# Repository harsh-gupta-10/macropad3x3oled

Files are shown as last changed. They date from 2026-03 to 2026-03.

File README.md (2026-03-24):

# Macropad 3×3 OLED

A 3×3 mechanical switch macropad with rotary encoders and OLED display, designed with CircuitPython on RP2040. Started as hand-wired prototype, evolving toward custom PCB design.

> **Repository**: https://github.com/harsh-gupta-10/macropad3x3oled

## Overview

This project documents the full design and build process for a compact macropad. Currently running as a functional hand-wired prototype with 9 programmable keys, 2 rotary encoders, and a 1.3" OLED display. The design is being formalized into a custom PCB using KiCAD 8.0 and JLCPCB manufacturing.

**Current status:** Hand-wired prototype complete and working. KiCAD schematic in progress.

## Features

- 3×3 mechanical switch grid (9 keys total)
- 2× EC11 rotary encoders with push buttons
- 1.3" I2C OLED display (SSD1306)
- 6 programmable layers (56 shortcuts total)
- USB Type-C connection
- CircuitPython firmware, fully modular
- Hot-configurable macros (no reflashing needed)

## Hardware Overview

**Current prototype components:**

| Component | Qty | Notes |
|---|-----|---|
| RP2040 microcontroller | 1 | Raspberry Pi Pico or compatible |
| Mechanical switches (MX) | 9 | User choice; same profile |
| EC11 rotary encoders | 2 | With integrated push switch |
| SSD1306 OLED display | 1 | 1.3" I2C interface |
| 1N4148 diodes | ~10 | Anti-ghosting matrix diodes |
| USB Type-C breakout | 1 | For power and data |
| Hook-up wire (22 AWG) | — | Solid core preferred |

**Key design notes:**
- Matrix scanning: 3 rows + 3 columns = 9 keys with just 6 GPIO pins
- I2C protocol: 2 wires (SDA, SCL) with 4.7kΩ pull-up resistors
- Power: 5V USB → 3.3V logic via linear regulator
- Debouncing: Software-based (20ms typical)

---

## Firmware Overview

Using CircuitPython on RP2040 for firmware. Clean Python implementation without build systems.

**Core functionality:**
- Matrix scanning: Reads 3×3 switch array, debounces input
- Encoder handling: Gray code decoding for 2 rotary encoders
- I2C display: Layer indicator and status on OLED
- USB HID: Presents as standard keyboard to operating system

**Firmware features:**
- 6 programmable layers for macro storage
- Real-time layer switching via encoder
- Per-key configurable actions
- Modular design (RGB, wireless support can be added)
- Configuration stored in `config.py`

## Usage / Workflow

**Basic operation:**
1. Connect via USB → device appears as keyboard
2. Press keys to trigger mapped macros/commands
3. Rotate encoders to switch layers or control functions
4. OLED shows current active layer

**Configuration:**
- Edit `config.py` in CircuitPython file system
- Reload to apply changes
- No firmware reflash needed

**Workflow example:**
- Layer 1: Productivity shortcuts (Alt+Tab, Copy/Paste, etc.)
- Layer 2: Media controls (Play, Volume, Next)
- Layer 3: Application launcher shortcuts
- Switch layers by rotating encoder

---

## Design & Build

### Hand-Wired Prototype Status

Current build is fully functional hand-wired setup. Validates all design decisions before PCB manufacturing.

**Current state:**
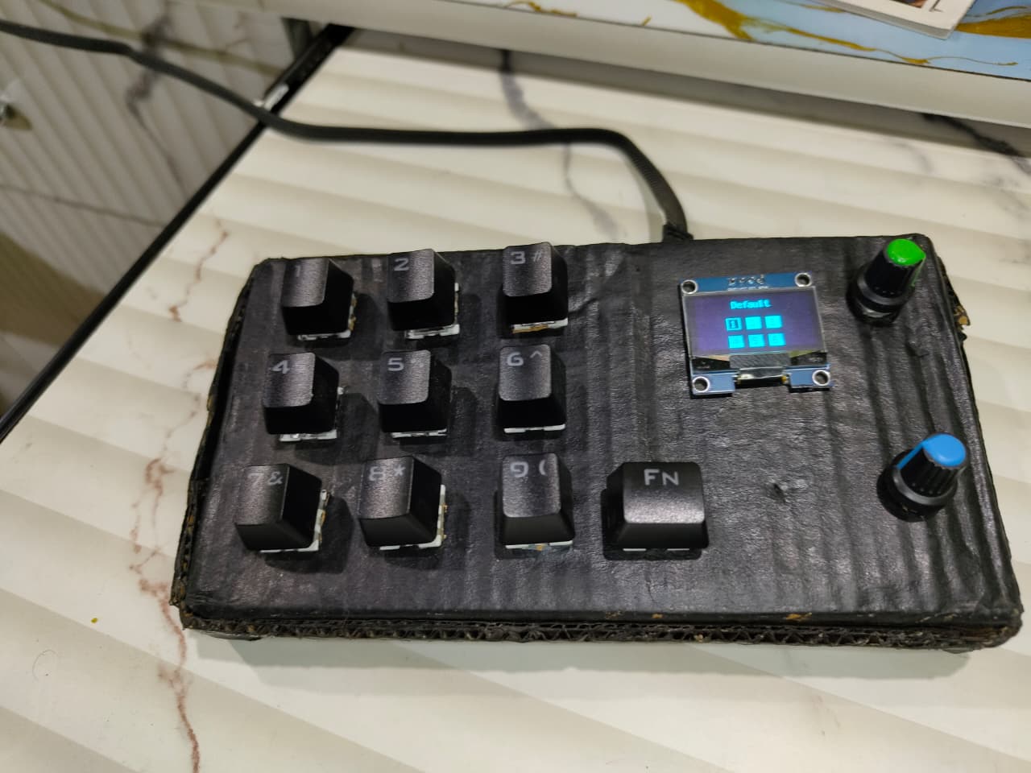
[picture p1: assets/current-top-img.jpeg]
Top view
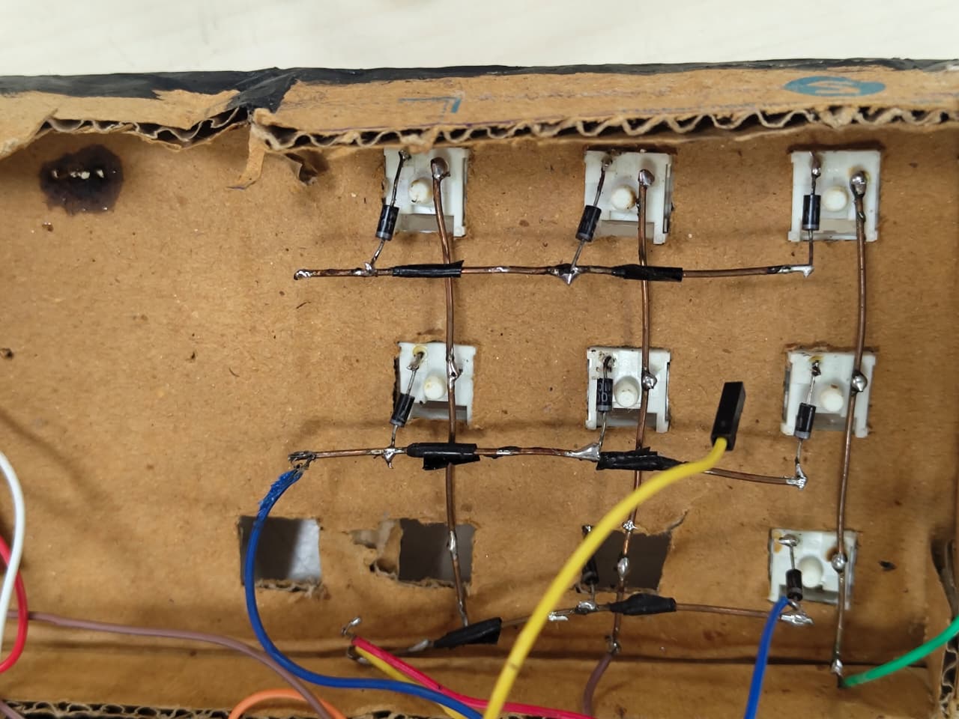
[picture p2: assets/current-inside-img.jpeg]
Internal view
 

### PCB / Schematic Design

Formalizing the design in KiCAD 8.0 for manufacturing through JLCPCB.

**Schematic phase:**
- Component selection and library setup
- Connection documentation (nets)
- Electrical rule checking (ERC)
- Footprint assignment

**Layout phase:**
- 2-layer PCB design (top: signals, bottom: ground plane)
- Design rules: 0.25mm trace width, 0.2mm clearance
- Dense ground via placement
- Manufacturing constraints (1mm board edge minimum)

**Signal integrity considerations:**
- I2C traces (SDA/SCL) routed together
- USB traces kept short and clean
- Test points for hardware debugging
- Decoupling capacitors near all power pins

**Manufacturing:**
- Gerber file generation from KiCAD
- Pre-order verification using Gerber viewers
- JLCPCB ordering: $5-20 for 5 prototype boards
- Expected turnaround: 7-10 days

### CAD / Design Files

The hardware case and enclosure are under development:
- Base design: `cad/macropad base v0.f3d` (Fusion 360)
- Top design: `cad/macro pad v3 top final.f3d` (Fusion 360)
- 3D printable base: `production/macropad base stl.3mf`

Files are in the `cad/` and `production/` directories. 3D printing materials: PLA or PETG recommended.

---

## BOM (Bill of Materials)

**Prototype assembly cost: $50-65 usd i got pricing from amazon.com(But in india i got all this under 25 usd)**

| Item | Qty | Unit Cost | Total | Source |
|---|-----|---|---|---|
| Mechanical switches (MX) | 9 | $1 | $9 | Outemu switches 2 pins |
| Keycaps (1u profile) | 1 set | $10-30 | $20 | Matched to switch type |
| EC11 rotary encoders | 2 | $3 | $6 | With push switch |
| SSD1306 OLED 1.3" display | 1 | $5 | $5 | I2C interface |
| RP2040 microcontroller | 1 | $5 | $5 | Raspberry Pi Pico |
| USB Type-C breakout board | 1 | $3 | $3 | For future PCB |
| 1N4148 signal diodes | 10 | $0.20 | $2 | Anti-ghosting matrix |
| Hook-up wire (22 AWG) | 1 spool | $5 | $5 | Solid core |
| USB cable | 1 | $3 | $3 | Programming/power |
| 3D printer filament | 50-100g | $0.02/g | $1-3 | PLA or PETG |
| **Total** | — | — | **$50-65** | — |

**PCB manufacturing (future):**
- Board fabrication: $5-20 for 5 boards via JLCPCB
- Component cost per unit: $30-40 
- Full assembled board cost (future): $50-60 per unit

---

## Future Improvements

- **4-layer PCB** — Better power distribution, reduced EMI
- **RGB LED matrix** — WS2812B per-key addressable LEDs
- **Metal enclosure** — CNC-milled aluminum case
- **Wireless support** — RP2040-W variant with Bluetooth
- **Battery charging** — LiPo connector with charge IC
- **Potentiometer option** — Analog knob instead of encoder
- **Configuration UI** — Desktop app for macro programming
- **Backlight** — Per-key or underglow LED strips

---

## Images / Gallery

**Current prototype build:**
- Top view: 
- Internal view: 
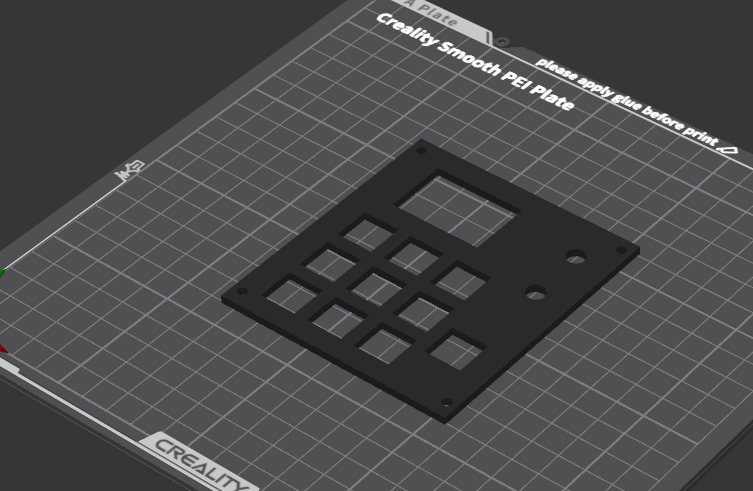
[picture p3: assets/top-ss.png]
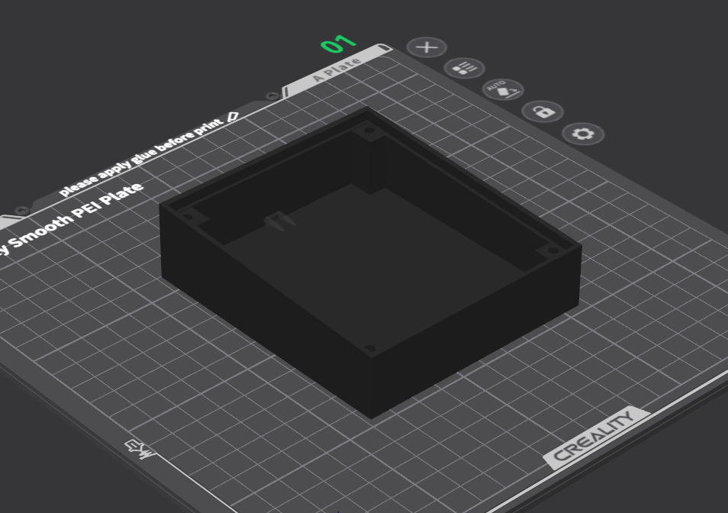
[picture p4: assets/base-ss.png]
- Reference photos:  

---

## Repo / Links

- **GitHub Repository**: https://github.com/harsh-gupta-10/macropad3x3oled
- **Raspberry Pi Pico Documentation**: https://www.raspberrypi.org/documentation/microcontrollers/raspberry-pi-pico.html
- **CircuitPython**: https://circuitpython.org/
- **KiCAD**: https://www.kicad.org/

---

##  Acknowledgements

Resources used:
- Raspberry Pi Foundation (RP2040 documentation)
- Circuit Python community
- KiCAD open-source PCB design tools

---

## License

MIT License - Feel free to use this design for your own projects.

See LICENSE file for details.

- Check diode orientation (trust me, you'll get this wrong)
- Test one key in isolation with a multimeter
- Verify GPIO pins match what the code expects
- That loose wire you "fixed" earlier? Check it again

### OLED display shows nothing

**Panic level:** Moderate

- I2C address mismatch? Run the I2C scanner code
- Pull-up resistors missing? Add 4.7kΩ on SDA and SCL
- Wrong I2C pins? Check code vs wiring
- Display DOA? Try another one (happened to me)

### Encoder spinning but not detecting

This one is fun:

- Gray code logic wrong? Complex but traceable
- Debounce timing too aggressive? Try different values
- Continuity bad? Test each pin with multimeter
- Encoder defect? Swap it out and test

### PCB doesn't work after assembly

**This is the fun one:**

- Cold solder joints? Use more flux and reheat
- Continuity bad? Multimeter everything
- Component orientation wrong? Some parts care deeply (ICs)
- Wrong component values? Double-check BOM vs assembled board
- Power OK but nothing works? Ground plane problem (probably)

### General debugging philosophy

1. Power first — Is there actually voltage where there should be?
2. Ground second — Is ground actually connected?
3. Logic third — Are signals even reaching their destinations?
4. Code last — Because 99% of the time it's hardware

Also, take a break before debugging. Frustrated you makes worse decisions.

---

## Contributing

I'd actually love feedback, suggestions, or just hearing about your own PCB adventures.

**Issues/PRs welcome for:**
- Design improvements (better component placement, better routing)
- Firmware enhancements
- Documentation clarifications
- "Hey I did this too" stories
- Cheaper alternative components
- Anything I'm doing wrong (seriously though)

---

## License

This project is open source. See the repository for details.

---

**Built by [Harsh Gupta](https://github.com/harsh-gupta-10)** ⌨️

If you're thinking about learning PCB design: start with something you actually want to use. Make it work first with whatever you have. Then make it pretty. The learning comes from the iteration, not the destination.

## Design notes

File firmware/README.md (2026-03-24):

# 🎛️ MacroPad RP2040 — Firmware

<p align="center">
  <b>Custom CircuitPython firmware for a DIY 3×3 macro pad built on the RP2040</b>
</p>

<p align="center">
  
  
  
</p>

> **Companion Software →** [MacroPad Configurator (Python + Tkinter)](https://github.com/harsh-gupta-10/macropad-software-python-tkinter)

---

## ✨ Features

| Feature | Details |
|---|---|
| **9-Key Matrix** | 3×3 cherry-style key grid with full per-key configurability |
| **6 Profiles** | Each profile stores 9 independent key actions, switchable on the fly |
| **OLED Display** | SH1106 128×64 showing profile selector bubbles + logo icon previews |
| **2 Rotary Encoders** | Volume control + profile navigation with rotate / click / hold actions |
| **Mic Toggle** | Dedicated button for mic mute (default: F13) |
| **JSON-Driven Config** | All key mappings and settings live in editable JSON files on the drive |

### Action Types

- ⌨️ **Keyboard Shortcuts** — single key or multi-key combo (e.g. `Ctrl+Shift+Esc`)
- 🚀 **Launch Software** — opens any app via Windows search (e.g. `notepad`, `chrome`)
- 📝 **Text Macros** — type text in single / line-by-line / paragraph mode, with optional Shift+Enter for apps like WhatsApp
- 🔊 **Media Controls** — volume up/down, mute, play/pause

---

## 📁 Project Structure

```text
├── code.py               # Main CircuitPython loop (display, matrix, encoders)
├── keyout.py             # Action engine (combos, software launch, text typing)
├── keysfile.json         # Profile + key action definitions (9 keys × 6 profiles)
├── special-keyout.json   # Encoder & mic button mappings
├── img/                  # BMP icons for OLED profile preview
│   ├── youtube-logo-bmp.bmp
│   ├── vscode-logo-bmp.bmp
│   ├── obs-logo-bmp.bmp
│   ├── volt-logo-bmp.bmp
│   ├── windows-logo-bmp.bmp
│   └── photoshop-logo-bmp.bmp
├── lib/                  # CircuitPython libraries
│   ├── adafruit_hid/
│   ├── adafruit_display_text/
│   ├── adafruit_displayio_sh1106.mpy
│   └── ...
├── main.py               # Legacy KMK firmware (inactive when code.py exists)
└── settings.toml         # CircuitPython board settings
```

---

## 🔌 Hardware Wiring

### OLED Display (SH1106, I2C, address `0x3C`)

| Signal | Pin |
|---|-----|
| SCL | GP9 |
| SDA | GP8 |

### Encoder 1 — Volume

| Signal | Pin |
|---|-----|
| A / B | GP14, GP15 |
| Button | GP17 |

### Encoder 2 — Display / Profile (Software Quadrature)

| Signal | Pin |
|---|-----|
| A / B | GP18, GP19 |
| Button | GP20 |

### Mic Toggle Button

| Signal | Pin |
|---|-----|
| Button | GP0 |

### 3×3 Key Matrix

| | GP1 (Col 0) | GP2 (Col 1) | GP3 (Col 2) |
|---|---|---|---|
| **GP4 (Row 0)** | Key 1 | Key 4 | Key 7 |
| **GP13 (Row 1)** | Key 3 | Key 6 | Key 9 |
| **GP6 (Row 2)** | Key 2 | Key 5 | Key 8 |

> 💡 If a physical button maps to the wrong action, edit `key_mapping` in `code.py` — don't rearrange `keysfile.json`.

---

## 🎮 Controls

| Input | Action |
|---|---|
| Encoder 1 — Rotate | Volume Up / Down |
| Encoder 1 — Click | Play / Pause |
| Encoder 1 — Hold (1s) | Mute |
| Encoder 2 — Rotate | Previous / Next Profile |
| Encoder 2 — Click | Switch Profile (shows icon for 1s) |
| Encoder 2 — Hold (1s) | Configurable special action |
| Mic Button | Toggle mic (default: F13) |
| Matrix Keys 1–9 | Execute current profile action |

---

## ⚙️ Configuration

### Profile Keys — `keysfile.json`

```json
{
  "settings": {
    "active_profiles": 6,
    "encoder_speeds": { "volume": 3, "display": 1 }
  },
  "profiles": {
    "0": {
      "1": { "name": "Close Tab", "key": ["ctrl", "w"] },
      "2": { "name": "Open VS Code", "key": ["windows"], "software": "vscode" },
      "3": {
        "name": "WhatsApp Msg",
        "key": ["text_input"],
        "action": "text_input",
        "text_content": "Hello!\nHow are you?",
        "text_type": "paragraph",
        "text_press_enter": true,
        "text_shift_enter": true
      }
    }
  }
}
```

**Action Formats:**

| Type | Required Fields |
|---|---|
| Key Combo | `key: ["ctrl", "s"]` |
| Software Launch | `key: ["windows"]`, `software: "notepad"` |
| Text Input | `action: "text_input"`, `text_content`, `text_type` (`single` / `line-by-line` / `paragraph`) |

> **`text_shift_enter: true`** — uses Shift+Enter for newlines instead of Enter. Essential for WhatsApp and similar apps where Enter sends the message.

### Special Inputs — `special-keyout.json`

```json
{
  "special_keys": {
    "volume_encoder_left":  { "name": "Volume Down", "key": ["media_volume_down"] },
    "display_encoder_right": { "name": "Next Profile", "action": "profile_next" }
  }
}
```

Each entry uses either `"key"` (keyboard/media token) or `"action"` (`profile_next`, `profile_prev`, `none`).

---

## 🚀 Getting Started

1. **Flash CircuitPython** onto your RP2040 board ([circuitpython.org](https://circuitpython.org/))
2. **Copy all project files** to the `CIRCUITPY` drive root
3. **Copy the `lib/` folder** to `CIRCUITPY/lib/`
4. **Edit your configs** — `keysfile.json` for key actions, `special-keyout.json` for encoders
5. **Save and go** — the board auto-reloads on file changes

> Use the companion [MacroPad Configurator](https://github.com/harsh-gupta-10/macropad-software-python-tkinter) app to edit profiles visually instead of hand-editing JSON.

---

## 🐛 Troubleshooting

| Problem | Fix |
|---|---|
| No key output | Confirm USB HID is detected by the OS. Check token spelling in JSON. |
| Wrong button mapping | Adjust `key_mapping` dict in `code.py` |
| Display not showing | Verify I2C wiring (GP9/GP8) and OLED address (`0x3C`) |
| Special actions not updating | Validate `special-keyout.json` syntax |
| Serial debug | Connect via serial console (e.g. PuTTY, `screen`) at 115200 baud |

---

## 📝 Notes

- Optimized for **Windows** shortcuts and search-bar-based software launching.
- `main.py` contains a legacy KMK firmware path — it does **not** run while `code.py` is present.
- Unsupported key tokens are logged over serial for easy debugging.

---

## 📄 License

MIT © [Harsh Gupta](https://github.com/harsh-gupta-10)

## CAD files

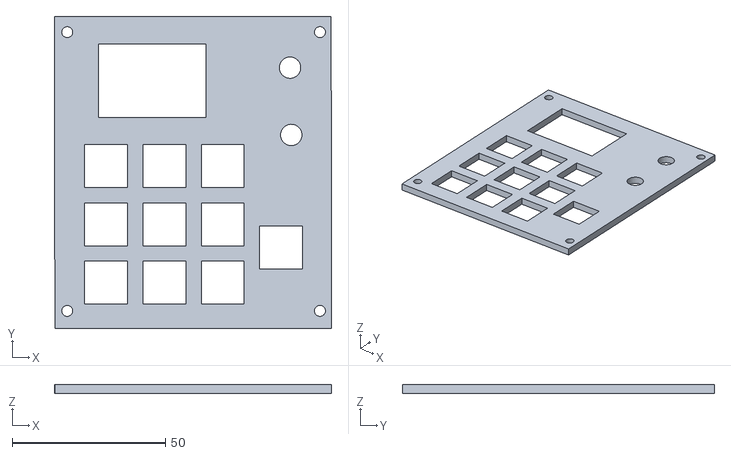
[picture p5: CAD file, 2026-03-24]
production/top macropad.stl
90.5 x 101.9 x 3.00

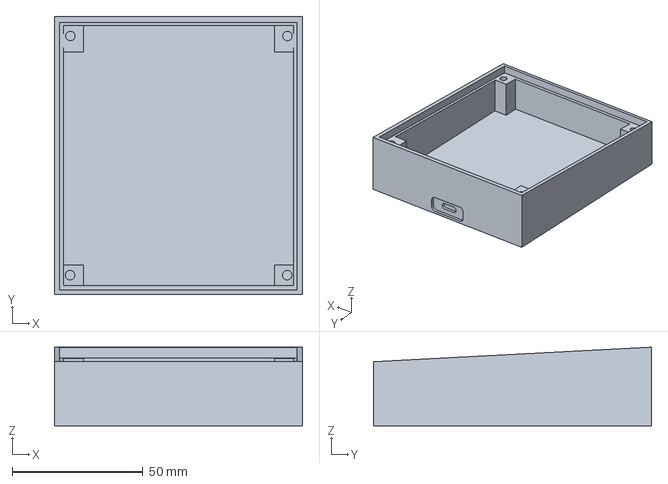
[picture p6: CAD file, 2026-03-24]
production/macropad base stl.3mf
94.9 x 106.4 x 30.1 mm

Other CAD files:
cad/macro pad v3 top final.f3d
cad/macropad base v0.f3d
production/macropad base stl.stl

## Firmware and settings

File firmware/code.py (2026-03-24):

import time
import json
import digitalio
import board
import busio
import usb_hid
import displayio
from adafruit_displayio_sh1106 import SH1106
from rotaryio import IncrementalEncoder
import terminalio
from adafruit_display_text import label
from digitalio import Direction, Pull
from adafruit_hid.consumer_control import ConsumerControl
from adafruit_hid.consumer_control_code import ConsumerControlCode
from adafruit_hid.keyboard import Keyboard
from adafruit_hid.keycode import Keycode
from keyout import execute_action

cc = ConsumerControl(usb_hid.devices)

encoder1 = IncrementalEncoder(board.GP14, board.GP15)
last_position_encoder1 = None

class SoftwareEncoder:
    def __init__(self, pinA, pinB):
        self.a = digitalio.DigitalInOut(pinA)
        self.b = digitalio.DigitalInOut(pinB)
        self.a.direction = digitalio.Direction.INPUT
        self.a.pull = digitalio.Pull.UP
        self.b.direction = digitalio.Direction.INPUT
        self.b.pull = digitalio.Pull.UP
        self.position = 0
        self._state = (int(self.a.value) << 1) | int(self.b.value)
        self._transition_accum = 0
        # Valid Gray-code transitions: +1/-1 quarter-steps, 0 for invalid/bounce.
        self._transition_table = (
            0, -1, 1, 0,
            1, 0, 0, -1,
            -1, 0, 0, 1,
            0, 1, -1, 0,
        )

    def update(self):
        current_state = (int(self.a.value) << 1) | int(self.b.value)
        if current_state != self._state:
            transition = (self._state << 2) | current_state
            quarter_step = self._transition_table[transition]
            if quarter_step:
                self._transition_accum += quarter_step
                if self._transition_accum >= 4:
                    self.position += 1
                    self._transition_accum = 0
                elif self._transition_accum <= -4:
                    self.position -= 1
                    self._transition_accum = 0
            self._state = current_state

softEncoder2 = SoftwareEncoder(board.GP18, board.GP19)
last_softPos2 = None

encoder1_button = digitalio.DigitalInOut(board.GP17)
encoder1_button.direction = Direction.INPUT
encoder1_button.pull = Pull.UP

encoder2_button = digitalio.DigitalInOut(board.GP20)
encoder2_button.direction = digitalio.Direction.INPUT
encoder2_button.pull = digitalio.Pull.UP

volume_hold_start = None
is_holding_volume_button = False
last_volume_button_state = True

display_hold_start = None
is_holding_display_button = False
last_display_button_state = True

last_profile_switch_time = 0
last_key_press_time = 0
debounce_delay = 0.2

displayio.release_displays()
i2c = busio.I2C(board.GP9, board.GP8)
display_bus = displayio.I2CDisplay(i2c, device_address=0x3C)
display = SH1106(display_bus, width=130, height=64)

def setup_button(pin):
    button = digitalio.DigitalInOut(pin)
    button.direction = digitalio.Direction.INPUT
    button.pull = digitalio.Pull.UP
    return button
def debounce_check(last_time, delay=0.5):
    return time.monotonic() - last_time > delay
last_mic_action_time = 0
last_encoder2_action_time = 0

mute_mic = setup_button(board.GP0)

cols = [digitalio.DigitalInOut(pin) for pin in [board.GP1, board.GP2, board.GP3]]
rows = [digitalio.DigitalInOut(pin) for pin in [board.GP4, board.GP13, board.GP6]]

for row in rows:
    row.direction = digitalio.Direction.OUTPUT
    row.value = False
for col in cols:
    col.direction = digitalio.Direction.INPUT
    col.pull = digitalio.Pull.DOWN

key_mapping = {
    (0, 0): 1, (0, 1): 4, (0, 2): 7,
    (1, 0): 3, (1, 1): 6, (1, 2): 9,
    (2, 0): 2, (2, 1): 5, (2, 2): 8,
}

# All available profile images (up to 10 profiles)
all_profile_images = [
    "/img/youtube-logo-bmp.bmp",
    "/img/vscode-logo-bmp.bmp",
    "/img/obs-logo-bmp.bmp",
    "/img/volt-logo-bmp.bmp",
    "/img/windows-logo-bmp.bmp",
    "/img/photoshop-logo-bmp.bmp",
    "/img/default-logo-7.bmp",
    "/img/default-logo-8.bmp",
    "/img/default-logo-9.bmp",
    "/img/default-logo-10.bmp",
]

def load_active_profiles():
    """Load the number of active profiles from keysfile.json"""
    try:
        with open("keysfile.json", "r") as f:
            data = json.load(f)
        settings = data.get("settings", {})
        active_profiles = settings.get("active_profiles", 6)
        # Ensure it doesn't exceed available images
        return min(active_profiles, len(all_profile_images))
    except Exception as e:
        print(f"Error loading active profiles: {e}")
        return 6

# Initialize image_files based on active profile count
active_profile_count = load_active_profiles()
image_files = all_profile_images[:active_profile_count]

selected_index = 0

SPECIAL_DEFAULTS = {
    "volume_encoder_left": {"name": "Volume Down", "key": ["media_volume_down"]},
    "volume_encoder_right": {"name": "Volume Up", "key": ["media_volume_up"]},
    "volume_encoder_click": {"name": "Play/Pause", "key": ["media_play_pause"]},
    "volume_encoder_hold": {"name": "Mute", "key": ["media_mute"]},
    "display_encoder_left": {"name": "Prev Profile", "action": "profile_prev"},
    "display_encoder_right": {"name": "Next Profile", "action": "profile_next"},
    "display_encoder_click": {"name": "Switch Profile", "action": "profile_next"},
    "display_encoder_hold": {"name": "No Action", "action": "none"},
    "mic_key": {"name": "Mic Toggle", "key": ["f13"]},
}


def load_special_actions():
    """Load editable special actions with safe defaults."""
    try:
        with open("special-keyout.json", "r") as f:
            data = json.load(f)
        actions = data.get("special_keys", {})
    except Exception as e:
        print(f"special-keyout.json load error: {e}")
        actions = {}

    merged = {}
    for action_id, default_entry in SPECIAL_DEFAULTS.items():
        merged[action_id] = default_entry.copy()
        if action_id in actions and isinstance(actions[action_id], dict):
            merged[action_id].update(actions[action_id])
    return merged


def normalize_token(token):
    return str(token).strip().lower().replace("-", "_").replace(" ", "_")


def token_to_keycode(token):
    token = normalize_token(token)
    key_map = {
        "ctrl": Keycode.CONTROL,
        "control": Keycode.CONTROL,
        "alt": Keycode.ALT,
        "shift": Keycode.SHIFT,
        "windows": Keycode.WINDOWS,
        "win": Keycode.WINDOWS,
        "esc": Keycode.ESCAPE,
        "escape": Keycode.ESCAPE,
        "tab": Keycode.TAB,
        "space": Keycode.SPACE,
        "spacebar": Keycode.SPACE,
        "enter": Keycode.ENTER,
        "backspace": Keycode.BACKSPACE,
        "up": Keycode.UP_ARROW,
        "down": Keycode.DOWN_ARROW,
        "left": Keycode.LEFT_ARROW,
        "right": Keycode.RIGHT_ARROW,
        "home": Keycode.HOME,
        "end": Keycode.END,
        "page_up": Keycode.PAGE_UP,
        "pagedown": Keycode.PAGE_DOWN,
        "page_down": Keycode.PAGE_DOWN,
        "insert": Keycode.INSERT,
        "delete": Keycode.DELETE,
        "print_screen": Keycode.PRINT_SCREEN,
    }

    if token in key_map:
        return key_map[token]

    if len(token) == 1 and "a" <= token <= "z":
        return getattr(Keycode, token.upper())
    if token.isdigit():
        digit_map = {
            "0": Keycode.ZERO,
            "1": Keycode.ONE,
            "2": Keycode.TWO,
            "3": Keycode.THREE,
            "4": Keycode.FOUR,
            "5": Keycode.FIVE,
            "6": Keycode.SIX,
            "7": Keycode.SEVEN,
            "8": Keycode.EIGHT,
            "9": Keycode.NINE,
        }
        return digit_map.get(token)
    if token.startswith("f") and token[1:].isdigit():
        try:
            return getattr(Keycode, token.upper())
        except AttributeError:
            return None

    return None


def execute_special_key_sequence(tokens):
    """Execute keyboard or media output for a special action entry."""
    if not tokens:
        return

    if isinstance(tokens, str):
        tokens = [tokens]

    if len(tokens) == 1:
        media_map = {
            "media_volume_up": ConsumerControlCode.VOLUME_INCREMENT,
            "media_volume_down": ConsumerControlCode.VOLUME_DECREMENT,
            "media_mute": ConsumerControlCode.MUTE,
            "media_play_pause": ConsumerControlCode.PLAY_PAUSE,
        }
        media_code = media_map.get(normalize_token(tokens[0]))
        if media_code is not None:
            cc.send(media_code)
            return

    keycodes = []
    for token in tokens:
        keycode = token_to_keycode(token)
        if keycode is None:
            print(f"Unsupported special token: {token}")
            return
        keycodes.append(keycode)

    kbd = Keyboard(usb_hid.devices)
    kbd.press(*keycodes)
    time.sleep(0.05)
    kbd.release_all()


def run_special_action(action_id, actions):
    """Run a mapped special action and return internal action string if present."""
    entry = actions.get(action_id, SPECIAL_DEFAULTS.get(action_id, {}))
    if "key" in entry:
        execute_special_key_sequence(entry.get("key", []))
        return None
    return entry.get("action", "none")


special_actions = load_special_actions()

def load_encoder_speeds():
    """Load encoder speed settings from keysfile.json"""
    try:
        with open("keysfile.json", "r") as f:
            data = json.load(f)
        settings = data.get("settings", {})
        encoder_speeds = settings.get("encoder_speeds", {})
        volume_speed = encoder_speeds.get("volume", 3)
        display_speed = encoder_speeds.get("display", 1)
        return volume_speed, display_speed
    except Exception as e:
        print(f"Error loading encoder speeds: {e}")
        # Return safe defaults
        return 3, 1

# Load encoder speeds on startup
VOLUME_STEPS_PER_TICK, DISPLAY_STEPS_PER_TICK = load_encoder_speeds()

is_showing_image = False
image_display_start = 0

def draw_bubbles(selected_index):
    splash = displayio.Group()
    bg_bitmap = displayio.Bitmap(display.width, display.height, 1)
    bg_palette = displayio.Palette(1)
    bg_palette[0] = 0x000000
    bg_sprite = displayio.TileGrid(bg_bitmap, pixel_shader=bg_palette, x=0, y=0)
    splash.append(bg_sprite)
    display.root_group = splash

    profile_name = get_profile_name(selected_index)
    profile_label = label.Label(terminalio.FONT, text=profile_name, color=0xFFFFFF)
    profile_label.x = (display.width - profile_label.bounding_box[2]) // 2
    profile_label.y = 10
    splash.append(profile_label)

    bubble_width = 17
    bubble_gap = 8
    total_bubbles = 6
    total_width = (bubble_width * 3) + (bubble_gap * 2)
    start_x = (display.width - total_width) // 2
    start_y = profile_label.y + profile_label.bounding_box[3] + 2

    for i in range(total_bubbles):
        x = start_x + (i % 3) * (bubble_width + bubble_gap)
        y = start_y + (i // 3) * (bubble_width + bubble_gap)
        is_selected = (i == selected_index)
        center = (bubble_width - 1) / 2
        radius = (bubble_width - 2) / 2
        inner_radius = max(radius - 1, 0)
        radius_sq = radius * radius
        inner_radius_sq = inner_radius * inner_radius

        if is_selected:
            bubble_bitmap = displayio.Bitmap(bubble_width, bubble_width, 2)
            bubble_palette = displayio.Palette(2)
            bubble_palette[0] = 0x000000
            bubble_palette[1] = 0xFFFFFF
            for px in range(bubble_width):
                for py in range(bubble_width):
                    dx = px - center
                    dy = py - center
                    dist_sq = (dx * dx) + (dy * dy)
                    if dist_sq <= radius_sq and dist_sq >= inner_radius_sq:
                        bubble_bitmap[px, py] = 1
                    elif dist_sq < inner_radius_sq:
                        bubble_bitmap[px, py] = 0
                    else:
                        bubble_bitmap[px, py] = 0
            bubble_sprite = displayio.TileGrid(bubble_bitmap, pixel_shader=bubble_palette, x=x, y=y)
            splash.append(bubble_sprite)
            number_label = label.Label(terminalio.FONT, text=str(i + 1), color=0xFFFFFF)
        else:
            bubble_bitmap = displayio.Bitmap(bubble_width, bubble_width, 2)
            bubble_palette = displayio.Palette(2)
            bubble_palette[0] = 0x000000
            bubble_palette[1] = 0xFFFFFF
            for px in range(bubble_width):
                for py in range(bubble_width):
                    dx = px - center
                    dy = py - center
                    if (dx * dx) + (dy * dy) <= radius_sq:
                        bubble_bitmap[px, py] = 1
                    else:
                        bubble_bitmap[px, py] = 0
            bubble_sprite = displayio.TileGrid(bubble_bitmap, pixel_shader=bubble_palette, x=x, y=y)
            splash.append(bubble_sprite)
            number_label = label.Label(terminalio.FONT, text=str(i + 1), color=0x000000)

        number_label.x = x + (bubble_width - number_label.bounding_box[2]) // 2
        number_label.y = y + (bubble_width - number_label.bounding_box[3]) // 2 + 6
        splash.append(number_label)

def get_profile_name(profile_index):
    profile_names = ["Default", "VSCode", "OBS", "Softwares", "Windows", "Photoshop"]
    return profile_names[profile_index] if 0 <= profile_index < len(profile_names) else "Profile"

def load_image(profile_index):
    image_file = image_files[profile_index]
    try:
        bitmap = displayio.OnDiskBitmap(open(image_file, "rb"))
        return bitmap
    except Exception as e:
        print(f"Error loading image {image_file}: {e}")
        return None

draw_bubbles(selected_index)

while True:
    # Volume control on encoder1
    position = encoder1.position
    if last_position_encoder1 is None:
        last_position_encoder1 = position
    delta1 = position - last_position_encoder1
    if delta1 != 0:
        step_count = abs(delta1) * VOLUME_STEPS_PER_TICK
        action_id = "volume_encoder_right" if delta1 > 0 else "volume_encoder_left"
        for _ in range(step_count):
            run_special_action(action_id, special_actions)
    last_position_encoder1 = position

    # Read software-based encoder2
    softEncoder2.update()
    pos2 = softEncoder2.position
    if last_softPos2 is None:
        last_softPos2 = pos2
    delta2 = pos2 - last_softPos2
    if delta2 != 0:
        action_id = "display_encoder_right" if delta2 > 0 else "display_encoder_left"
        step_count = abs(delta2) * DISPLAY_STEPS_PER_TICK
        for _ in range(step_count):
            internal_action = run_special_action(action_id, special_actions)
            if internal_action == "profile_next":
                selected_index = (selected_index + 1) % len(image_files)
                draw_bubbles(selected_index)
            elif internal_action == "profile_prev":
                selected_index = (selected_index - 1) % len(image_files)
                draw_bubbles(selected_index)
        last_softPos2 = pos2

    #mic mute switch logic
    if not mute_mic.value and debounce_check(last_mic_action_time):
        run_special_action("mic_key", special_actions)
        last_mic_action_time = time.monotonic()
          
    current_volume_button_state = encoder1_button.value
    
    if not current_volume_button_state and last_volume_button_state:
        volume_hold_start = time.monotonic()
        is_holding_volume_button = True
    if current_volume_button_state and not last_volume_button_state:
        if is_holding_volume_button and (time.monotonic() - volume_hold_start) < 1:
            run_special_action("volume_encoder_click", special_actions)
        volume_hold_start = None
        is_holding_volume_button = False
    if is_holding_volume_button and volume_hold_start and (time.monotonic() - volume_hold_start) >= 1:
        run_special_action("volume_encoder_hold", special_actions)
        volume_hold_start = None
        is_holding_volume_button = False
    last_volume_button_state = current_volume_button_state
    
    # encoder2 button logic (click/hold)
    current_display_button_state = encoder2_button.value
    if not current_display_button_state and last_display_button_state and debounce_check(last_encoder2_action_time, 0.2):
        display_hold_start = time.monotonic()
        is_holding_display_button = True
    if current_display_button_state and not last_display_button_state:
        if is_holding_display_button and display_hold_start and (time.monotonic() - display_hold_start) < 1:
            internal_action = run_special_action("display_encoder_click", special_actions)
            if internal_action == "profile_next":
                selected_index = (selected_index + 1) % len(image_files)
            elif internal_action == "profile_prev":
                selected_index = (selected_index - 1) % len(image_files)

            if internal_action in ("profile_next", "profile_prev"):
                bitmap = load_image(selected_index)
                if bitmap:
                    splash = displayio.Group()
                    image_sprite = displayio.TileGrid(bitmap, pixel_shader=bitmap.pixel_shader)
                    image_sprite.x = (display.width - bitmap.width) // 2
                    image_sprite.y = (display.height - bitmap.height) // 2
                    splash.append(image_sprite)
                    display.root_group = splash
                    is_showing_image = True
                    image_display_start = time.monotonic()
            last_encoder2_action_time = time.monotonic()
        display_hold_start = None
        is_holding_display_button = False

    if is_holding_display_button and display_hold_start and (time.monotonic() - display_hold_start) >= 1:
        internal_action = run_special_action("display_encoder_hold", special_actions)
        if internal_action == "profile_next":
            selected_index = (selected_index + 1) % len(image_files)
            draw_bubbles(selected_index)
        elif internal_action == "profile_prev":
            selected_index = (selected_index - 1) % len(image_files)
            draw_bubbles(selected_index)
        display_hold_start = None
        is_holding_display_button = False
        last_encoder2_action_time = time.monotonic()

    last_display_button_state = current_display_button_state
        
    #profile
    for row_index, row_pin in enumerate(rows):
        row_pin.value = True
        for col_index, col_pin in enumerate(cols):
            if col_pin.value and (time.monotonic() - last_key_press_time > debounce_delay):
                key_number = key_mapping[(row_index, col_index)]
                if key_number == 6:
                    print(f"[MATRIX] *** KEY 6 DETECTED at ({row_index}, {col_index}) ***")
                execute_action(key_number, selected_index)
                last_key_press_time = time.monotonic()
        row_pin.value = False

    # Add this code at the end of the while loop to check if it's time to switch back to bubbles
    if is_showing_image and (time.monotonic() - image_display_start) >= 1.0:
        draw_bubbles(selected_index)
        is_showing_image = False

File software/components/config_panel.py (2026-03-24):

import tkinter as tk
from tkinter import ttk, messagebox, filedialog
from engine import update_profile_key, load_special_keys, update_special_key, load_settings, update_settings
import os

class ConfigPanel:
    def __init__(self, parent, app=None):
        self.parent = parent
        self.app = app  # Reference to main app
        self.special_action_options = {
            "Volume Encoder - Left Rotation": "volume_encoder_left",
            "Volume Encoder - Right Rotation": "volume_encoder_right",
            "Volume Encoder - Click": "volume_encoder_click",
            "Volume Encoder - Hold": "volume_encoder_hold",
            "Display Encoder - Left Rotation": "display_encoder_left",
            "Display Encoder - Right Rotation": "display_encoder_right",
            "Display Encoder - Click": "display_encoder_click",
            "Display Encoder - Hold": "display_encoder_hold",
            "Mic Key (Fixed Button)": "mic_key",
        }
        self.create_ui()

    def create_ui(self):
        """Create the key changer panel."""
        self.parent.option_add("*Font", "{Segoe UI} 10")
        self.parent.option_add("*TCombobox*Listbox.background", "#0B1220")
        self.parent.option_add("*TCombobox*Listbox.foreground", "#E2E8F0")
        self.parent.option_add("*TCombobox*Listbox.selectBackground", "#0EA5E9")
        self.parent.option_add("*TCombobox*Listbox.selectForeground", "#082F49")

        style = ttk.Style()
        try:
            style.theme_use("clam")
        except Exception:
            pass

        style.configure("App.TNotebook", background="#0F172A", borderwidth=0)
        style.configure("App.TNotebook.Tab", background="#1E293B", foreground="#E2E8F0", padding=(6, 7), font=("Segoe UI", 9, "bold"))
        style.map(
            "App.TNotebook.Tab",
            background=[("selected", "#0EA5E9")],
            foreground=[("selected", "#082F49")],
        )
        style.configure("App.TCombobox", fieldbackground="#0B1220", background="#0B1220", foreground="#E2E8F0", arrowcolor="#E2E8F0", bordercolor="#334155", lightcolor="#334155", darkcolor="#334155")
        style.map(
            "App.TCombobox",
            fieldbackground=[("readonly", "#0B1220")],
            foreground=[("readonly", "#E2E8F0")],
            selectforeground=[("readonly", "#E2E8F0")],
            selectbackground=[("readonly", "#0B1220")],
        )

        config_frame = tk.Frame(self.parent, bg="#111827", bd=1, relief="ridge", highlightbackground="#1F2937", highlightthickness=1)
        config_frame.place(x=540, y=10, width=390, height=430)

        tk.Label(config_frame, text="Key Changer Panel", bg="#111827", fg="#F8FAFC", font=("Segoe UI", 13, "bold"), pady=6).pack()

        self.tab_control = ttk.Notebook(config_frame, style="App.TNotebook")  # Save as instance variable
        self.tab_control.pack(expand=1, fill="both")

        # Tab for Basic Configuration
        basic_tab = tk.Frame(self.tab_control, bg="#0F172A")
        self.tab_control.add(basic_tab, text="Basic Config")

        # Name Input Box at the top
        self.text_box_label = tk.Label(basic_tab, text="Name(Use):", bg="#0F172A", fg="#E2E8F0", font=("Segoe UI", 11, "bold"))
        self.text_box_label.pack(pady=5)

        self.text_box = tk.Text(basic_tab, height=1.2, width=30, wrap="word", bg="#0B1220", fg="#E2E8F0", insertbackground="#E2E8F0", font=("Segoe UI", 10), relief="flat")
        self.text_box.pack(pady=5)

        # Category Dropdown (First Dropdown)
        tk.Label(basic_tab, text="Select Category", bg="#0F172A", fg="#E2E8F0", font=("Segoe UI", 10, "bold")).pack(pady=5)
        self.key_category_var = tk.StringVar()
        self.key_category_var.set("Alphabets")  # Default Category

        category_dropdown = ttk.Combobox(basic_tab, textvariable=self.key_category_var, state="readonly", style="App.TCombobox")
        category_dropdown["values"] = ["Alphabets", "Numbers", "Symbols", "F1-F24", "Navigation Keys", 
                                       "Modifiers", "System Keys", "Media Keys", "Numpad Keys", "Other Keys"]
        category_dropdown.pack(pady=5)
        
        # Specific Keys Dropdown (Second Dropdown)
        tk.Label(basic_tab, text="Select Key", bg="#0F172A", fg="#E2E8F0", font=("Segoe UI", 10, "bold")).pack(pady=5)
        self.specific_keys_var = tk.StringVar()
        self.specific_keys_dropdown = ttk.Combobox(basic_tab, textvariable=self.specific_keys_var, state="readonly", style="App.TCombobox")
        self.specific_keys_dropdown.pack(pady=5)

        # Update the second dropdown based on the selected category
        self.update_specific_keys()
        category_dropdown.bind("<<ComboboxSelected>>", self.update_specific_keys)

        # Save Button
        save_button = tk.Button(basic_tab, text="Save", bg="#0EA5E9", fg="#082F49", font=("Segoe UI", 10, "bold"), relief="flat", command=self.save_config)
        save_button.pack(pady=10)

        # Tab for Advanced Configuration
        advanced_tab = tk.Frame(self.tab_control, bg="#0F172A")
        self.tab_control.add(advanced_tab, text="Advanced")

        # Create inner scrollable frame
        advanced_scroll_frame = tk.Frame(advanced_tab, bg="#0F172A")
        advanced_scroll_frame.pack(side="top", fill="x", expand=False, pady=5)

        # Name input box at the top
        self.advanced_text_label = tk.Label(advanced_scroll_frame, text="Name(Use):", bg="#0F172A", fg="#E2E8F0", font=("Segoe UI", 11, "bold"))
        self.advanced_text_label.pack(pady=5)

        self.advanced_text_box = tk.Text(advanced_scroll_frame, height=1.2, width=30, wrap="word", bg="#0B1220", fg="#E2E8F0", insertbackground="#E2E8F0", font=("Segoe UI", 10), relief="flat")
        self.advanced_text_box.pack(pady=10)

        # Radio buttons for key combination options
        self.key_combo_var = tk.IntVar(value=2)
        radio_frame = tk.Frame(advanced_scroll_frame, bg="#0F172A")
        radio_frame.pack(pady=5)
        
        tk.Radiobutton(radio_frame, text="2 Keys", variable=self.key_combo_var, value=2, 
                      bg="#0F172A", fg="#E2E8F0", selectcolor="#0B1220", 
                      command=self.update_key_dropdowns).pack(side="left", padx=20)
        tk.Radiobutton(radio_frame, text="3 Keys", variable=self.key_combo_var, value=3, 
                      bg="#0F172A", fg="#E2E8F0", selectcolor="#0B1220",
                      command=self.update_key_dropdowns).pack(side="left", padx=20)

        # Frame for Dropdowns (doesn't expand vertically)
        self.dropdown_frame = tk.Frame(advanced_scroll_frame, bg="#0F172A")
        self.dropdown_frame.pack(pady=10, fill="none", expand=False)
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

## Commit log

2026-03-24 Add images of current prototype build
2026-03-24 Add Keypad, Profiles, and Status Bar components
    - Implemented KeypadSection for managing keypad buttons and profiles.
    - Created ProfilesSection for displaying and selecting user profiles.
    - Developed StatusBar for monitoring connection status and user actions.
    - Added utility functions for loading profiles and saving key configurations.
